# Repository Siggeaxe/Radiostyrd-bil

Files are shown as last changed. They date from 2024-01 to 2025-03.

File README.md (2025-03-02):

# Remote-Controlled Hand-Gesture Operated Car!

This project showcases a wirelessly controlled car operated through a glove-mounted remote that translates hand movements into driving commands.

### How It Works  
The glove remote determines the user’s hand orientation (attitude) using an MPU6050 Inertial Measurement Unit (IMU), which consists of a gyroscope and accelerometer. The accelerometer measures Earth's gravity to estimate the glove’s tilt angle using trigonometry. These calculated angles are then processed by an Atmega328p microcontroller, which converts them into control signals.  

The control signals are wirelessly transmitted via Bluetooth to the car, where they are received and interpreted to adjust motor speed and direction. The car’s propulsion system consists of an H-bridge motor driver, which regulates power to the four independent wheel motors, allowing smooth and precise movement.  

| The controller circuit mounted on a prototype board with a red LED indicating connection to the car | The controller circuit mounted on a glove |  
| --- | --- |
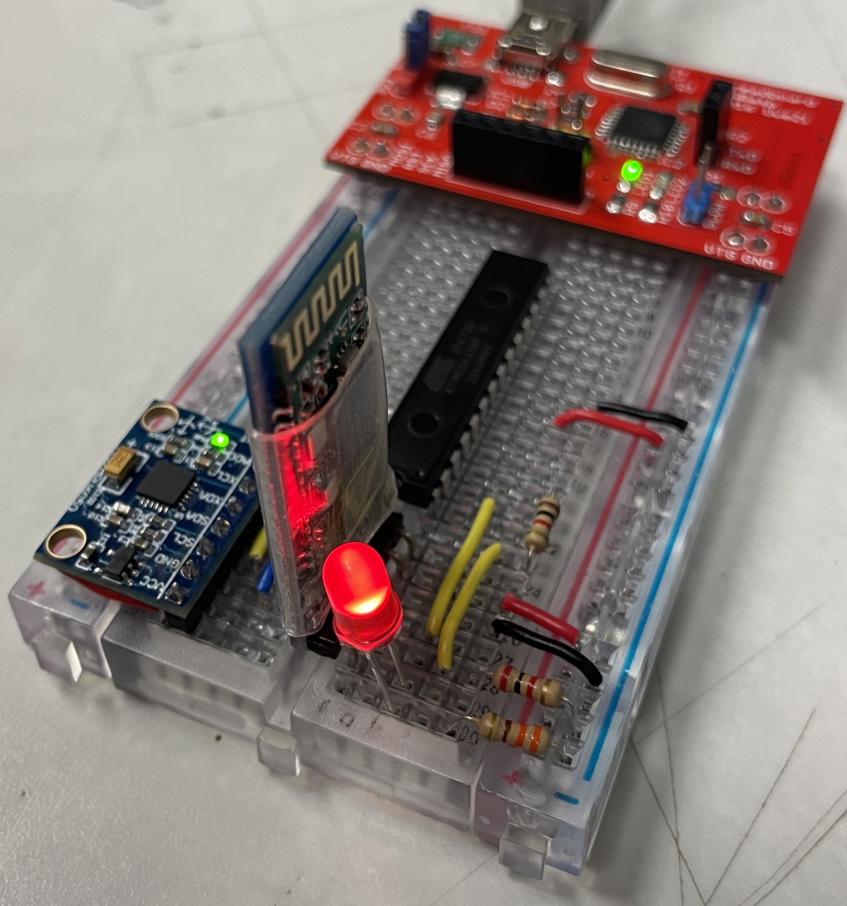
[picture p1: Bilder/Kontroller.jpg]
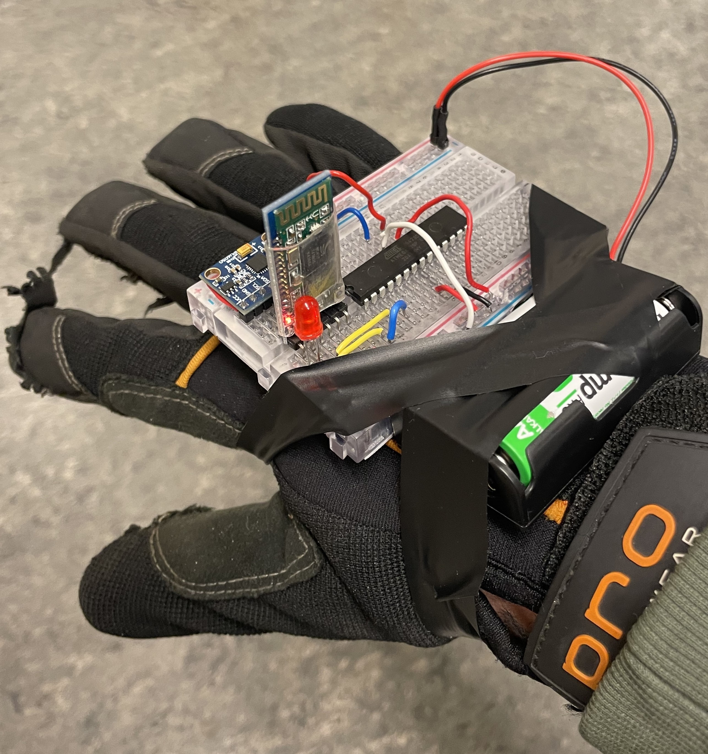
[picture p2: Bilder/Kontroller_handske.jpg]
|  |  |  

| The car with the circuit connected on prototype boards, powered by eight AA batteries, mounted on a plastic chassis |  
| --- |  
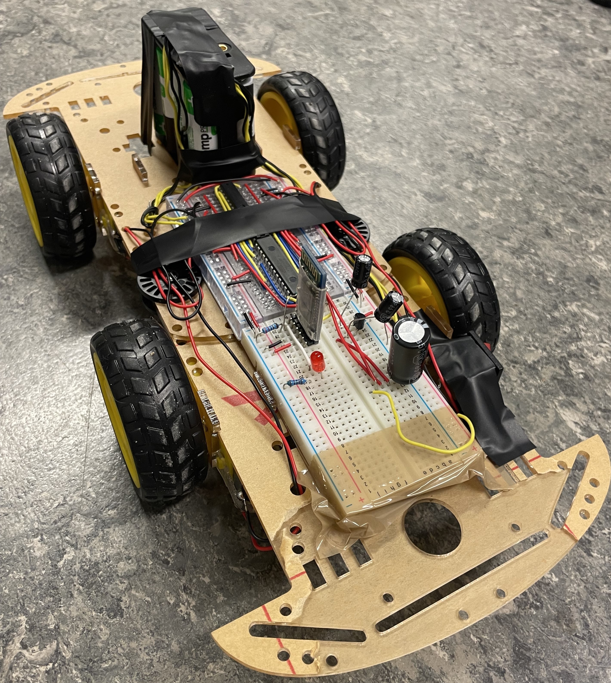
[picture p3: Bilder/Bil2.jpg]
|  |  

| Circuit diagram of the car | Circuit diagram of the controller |  
| --- | --- |
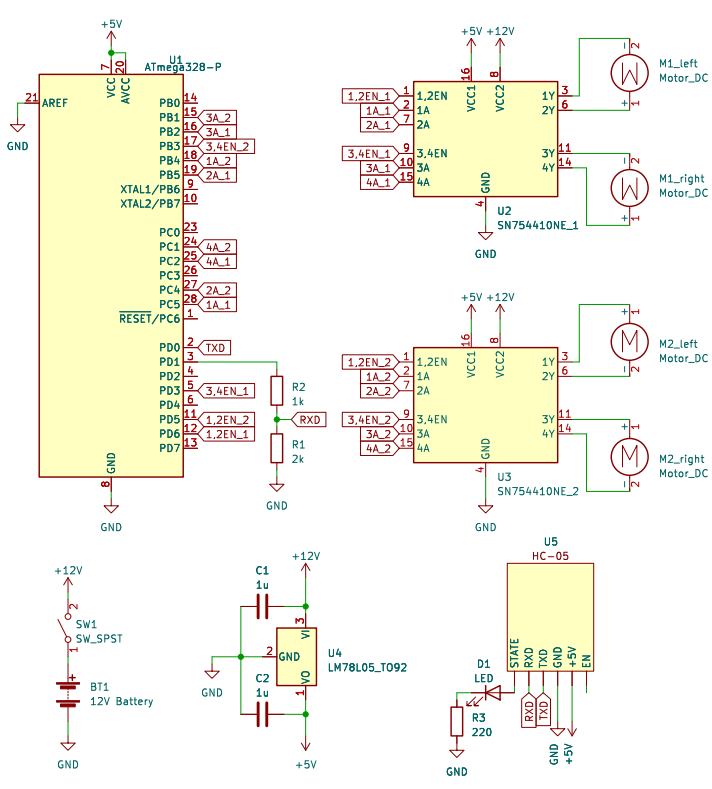
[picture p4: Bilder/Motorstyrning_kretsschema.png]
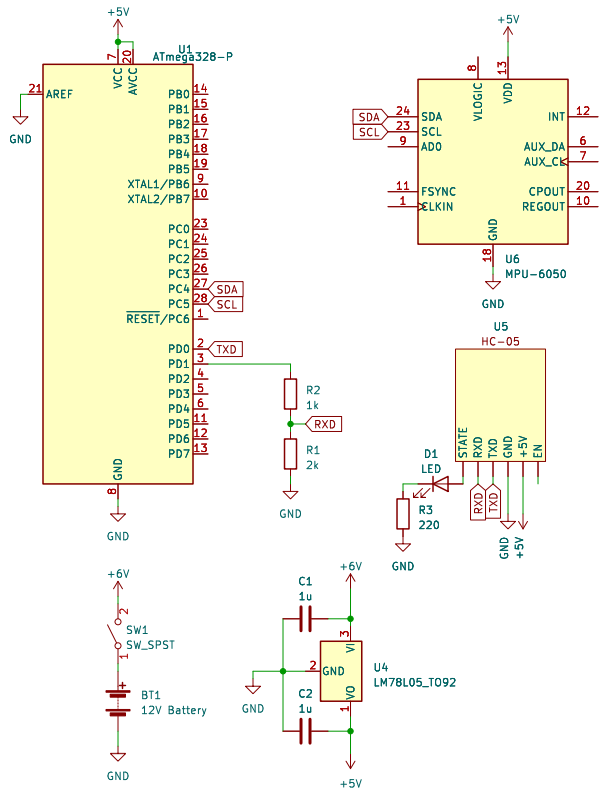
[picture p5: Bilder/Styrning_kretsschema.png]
|  |  |

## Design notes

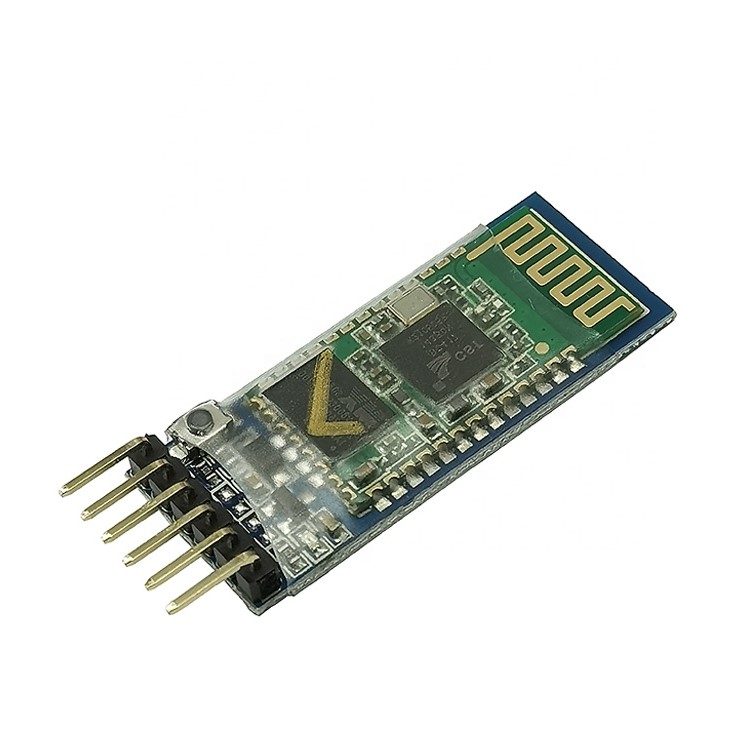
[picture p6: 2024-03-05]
Bilder/HC05.jpg

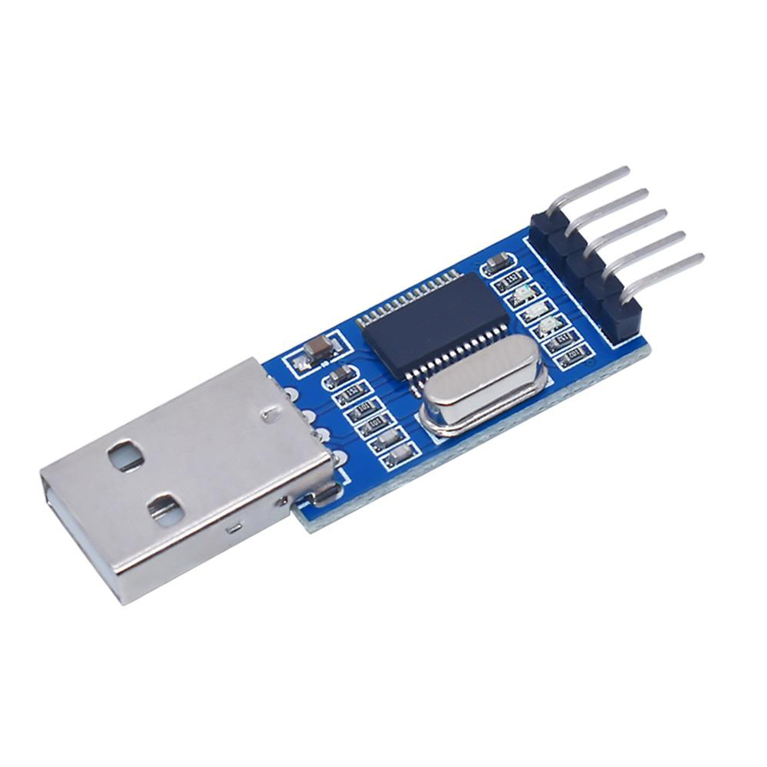
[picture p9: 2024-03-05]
Bilder/USB-TTL.jpg

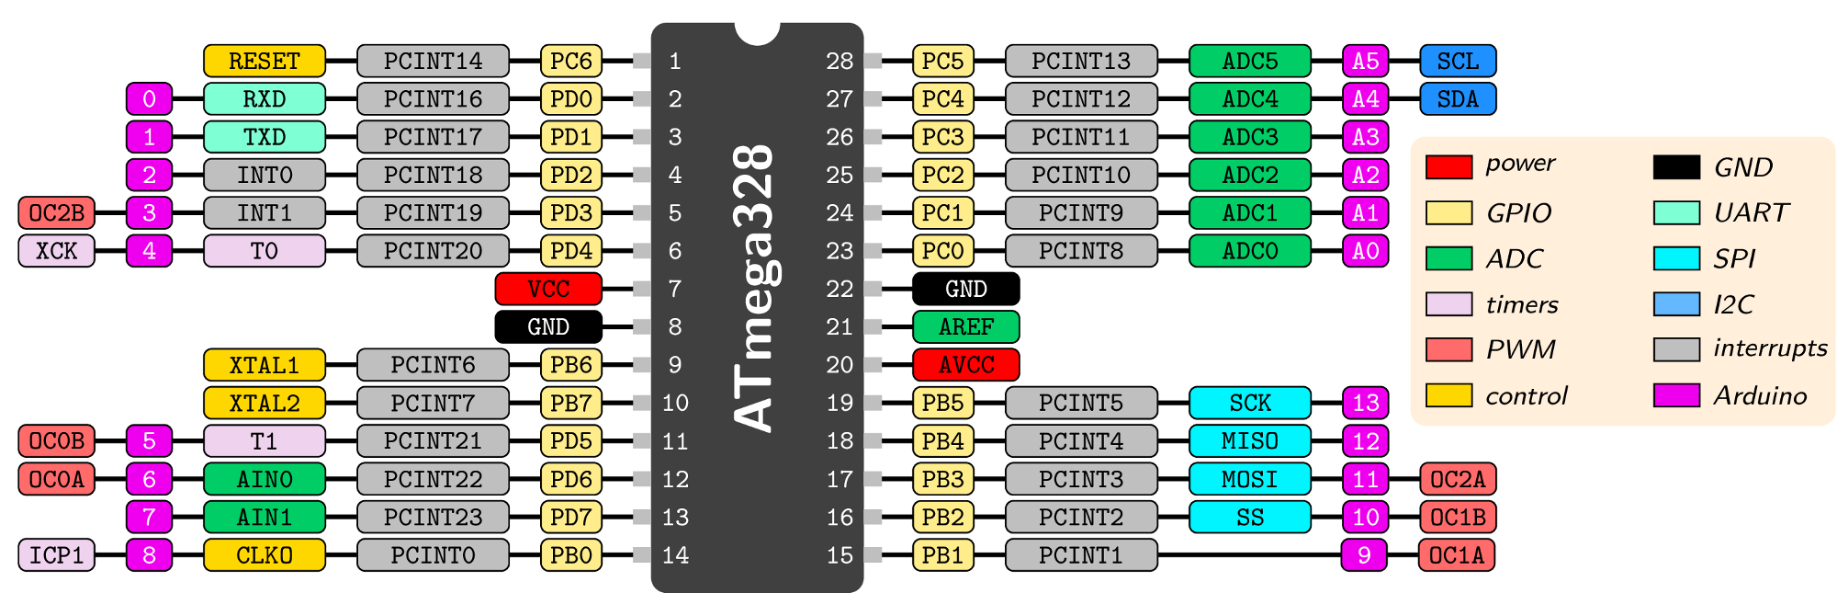
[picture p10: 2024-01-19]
Bilder/20211102_atmega328.png

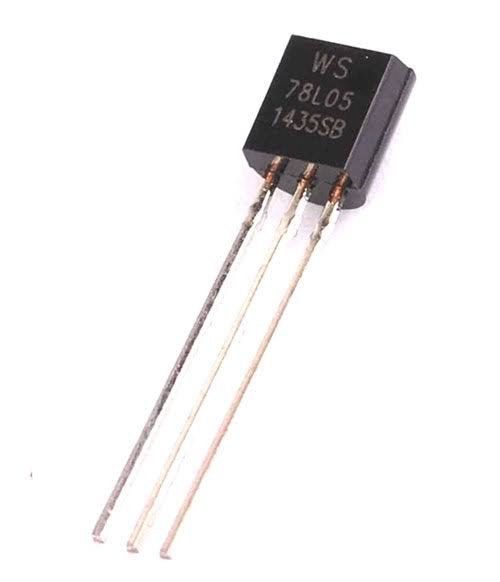
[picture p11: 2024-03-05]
Bilder/78L05.jpeg

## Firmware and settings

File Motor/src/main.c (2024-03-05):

#include <avr/io.h>
#include <stdio.h>
#include <util/delay.h>
#include <avr/interrupt.h>
#include <stdlib.h>
#include "i2cmaster.h"
#include "twimaster.c"
#include <mpu.inc>
#include "uart.c"
#include "uart.h"

#define AVG 8
#define UART_BAUD_RATE 9600      

volatile float x_angle=0,y_angle=0;
volatile int32_t accelX=0,accelY=0,accelZ=0;
volatile int16_t Ax=0, Ay=0, Az=0;
volatile uint8_t k =0;

void init(void){
  //PB 1,2,4,5 - framåt ports
  //PC 1,2,4,5 - Bakåt ports, Xor med forward för att altid ha en high
  //PD 3,5,6 & PB 3 - PWM portar till Enable pin på drivarkretsen
  DDRB = 0b00111110;
  DDRD = 0b01101000;
  DDRC = 0b00110110;

  // setting up TIMER0
  TCCR0A = (1 << COM0A1 ) | (0 << COM0A0 ) | (1 << COM0B1 ) | (0 << COM0B0 )
            | (1 << WGM01 ) | (1 << WGM00 );
  TCCR0B = (0 << WGM02 ) | (1 << CS02) | (0 << CS01) | (1 << CS00 );

  TCCR2A = (1 << COM2A1 ) | (0 << COM2A0 ) | (1 << COM2B1 ) | (0 << COM2B0 )
            | (1 << WGM21 ) | (1 << WGM20 );
  TCCR2B = (0 << WGM22 ) | (1 << CS22) | (0 << CS21) | (1 << CS20 );

  uart_init( UART_BAUD_SELECT(UART_BAUD_RATE,F_CPU) ); 
  sei();
}

int main(void){
  init();
  OCR0A = 0;
  OCR0B = 0;
  OCR2A = 0;
  OCR2B = 0;
  uint8_t forward = 0b00110110;
  uint8_t motor_right = 0b00110000;
  uint8_t motor_left = 0b00000110;
  uint8_t right = 0;
  uint8_t left = 0;
  uint8_t direction = 0;
  uint16_t timer = 0;
  unsigned int c;

  while(1){
    c = uart_getc();

    if (c & UART_NO_DATA){  // no data available from UART (lower byte: received byte from ringbuffer, 
                            // higher byte: last receive status. Om du inte fattar holla på Peter Fleury:s UART dokummentation!!!)
      if (timer >= 500){
        right = 0;
        left = 0;
        direction = 0;
      }
      else{timer++;}
      _delay_ms(1);      
    }
    else{
      timer = 0;
      switch(c & 0b11000000){
        case 0b01000000:
          right = c<<2;
          break;
        case 0b10000000:
          left = c<<2;
          break;
        case 0b11000000:
          direction = c & 0b00000111;
          break;
      }
    }

    if (direction & 0x01){
      PORTB = forward;
      PORTC = 0x00;
    }
    else if (direction & 0x02){
      PORTB = motor_right; 
      PORTC = forward^motor_right;
    }
    else if(direction & 0x04){
      PORTB = motor_left;
      PORTC = forward^motor_left;
    }
    else{
      PORTB = 0x00;
      PORTC = forward;     
    }

    OCR0A = right;
    OCR0B = right;

    OCR2A = left;
    OCR2B = left;

  }
}

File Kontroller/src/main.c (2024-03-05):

#include <avr/io.h>
#include <avr/interrupt.h>
#include <util/delay.h>
#include <uart.h>
#include <i2cmaster.h>
#include <twimaster.c>
#include <mpu.inc>
#include <stdio.h>
#include <stdlib.h>
#include <avr/interrupt.h>
#include <avr/wdt.h>        

#define UART_BAUD_RATE 9600      
#define AVG 8

volatile int32_t accelX=0, accelY=0, accelZ=0;
volatile int16_t Ax=0, Ay=0, right = 0, left = 0;

void get_data(void){
  accelX = (MPU6050_readSensor16(MPU6050_ACCEL_XOUT_L,MPU6050_ACCEL_XOUT_H) + (AVG-1)*accelX)/AVG;
  accelY = (MPU6050_readSensor16(MPU6050_ACCEL_YOUT_L,MPU6050_ACCEL_YOUT_H) + (AVG-1)*accelY)/AVG;
  accelZ = (MPU6050_readSensor16(MPU6050_ACCEL_ZOUT_L,MPU6050_ACCEL_ZOUT_H) + (AVG-1)*accelZ)/AVG;
}

void scaled_data(){
  Ax = accelX/64;
  Ay = accelY/64;

  right = (Ax + Ay);
  left = (Ax - Ay);
}

void init()
{
  // DDRB = 0x00000001;  // LED
  uart_init( UART_BAUD_SELECT(UART_BAUD_RATE,F_CPU) ); 
  i2c_init();
  MPU6050_writeSensor(MPU6050_PWR_MGMT_1, 0);
  
  cli();
  //reset watchdog
  wdt_reset();
  //set up WDT interrupt
  WDTCSR = (1<<WDCE) | (1<<WDE) |(0<<WDIE) | (0<<WDP3)
          | (0<<WDP2) | (1<<WDP1) | (1<<WDP0);
  //Enable global interrupts
  sei();
}

int main(void)
{
  uint8_t dir = 0, tempL = 0, tempR = 0;

  init();

  for(;;)
  {
    wdt_reset();
    get_data();
    scaled_data();

    // Left, right  
    if (abs(right)>255){
      right = 255*((right > 0) - (right < 0));
    }
    if (abs(left)>255){
      left = 255*((left > 0) - (left < 0));
    }

    // Direction
    if (right>=0 && left>=0){
      dir = 1;
    }
    else if (right>=0 && left < 0){
      dir = 2;
    }
    else if(right<0 && left>=0){
      dir = 4;
    }
    else{
      dir = 8;
    }

    tempL = abs(left);
    tempR = abs(right);

    // Code the messages
    tempL = (tempL >> 2) | 0b10000000;
    tempR = (tempR >> 2) | 0b01000000;
    dir = dir | 0b11000000;

    // Send through UART
    uart_putc(tempR);
    uart_putc(tempL);
    uart_putc(dir);
    uart_putc('\r');

    _delay_ms(5);
  }

  return 0;
}

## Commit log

2024-01-19 Added motor files
2024-01-19 ATmega pin OUT
2024-01-19 Påbörjat PWM och krestbild
    [Bil-schematic.kicad_pcb, Bil-schematic.kicad_sch]
2024-01-24 PWM är uppsatt med enkel bräkning, behöver förbättras
2024-02-06 Motor 3 är aktuell
2024-02-14 la till en kommentar
2024-02-23 Rensat i koden + bilen stannar när inga UART tas emot
2024-03-05 Added watchdog timer
2024-03-05 Namnbyte och sortering av filer
    [Bil-schematic.kicad_pcb, Bil-schematic.kicad_sch, Motorstyrning.kicad_pcb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]
